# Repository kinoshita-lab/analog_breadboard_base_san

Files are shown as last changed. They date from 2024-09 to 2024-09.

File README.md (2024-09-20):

# Analog Breadboard Base san

[日本語](README.ja.md)

You have two cows. You want to build analog circuit with both positive/negative rails...

Here it is!

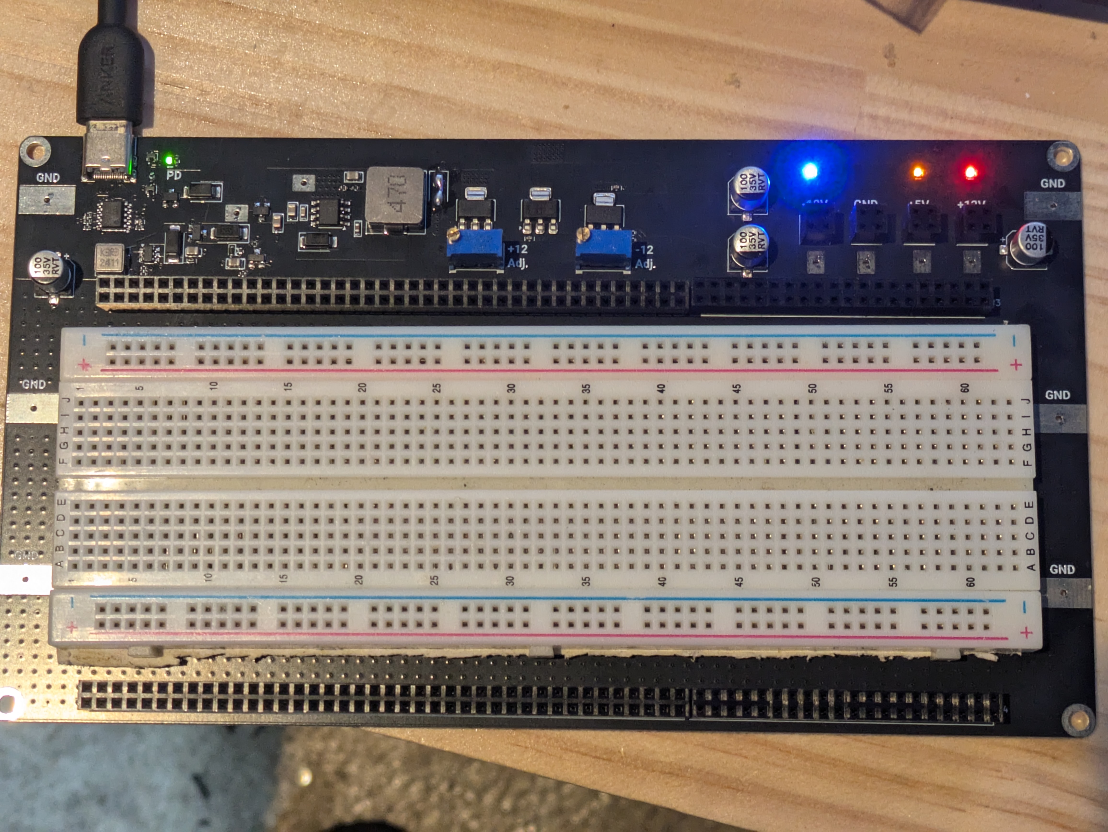
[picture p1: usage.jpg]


## Features

- USB PD supported. Use 15V if the PD power source if available
- When not, internal DC-DC can supply 15V(with a limited power which USB port can supply)
  - Confirmed working with M2 Macbook Air and Chuwi Freebook(meaning you can use this board with normal USB type-C port on your PC)
- Has 15V(unregulated) and -15V(unregulated) test point for the convinience of advanced users..

## Kit Contents

- Pre-assembled circuit board
- 2x2 pin socket connector(4 pcs.)
- 2x40 pin socket connector(2 pcs.)
- 2x20 pin socket connector(2 pcs.)

## What you will need

- USB Type-C Adapter(PD 15V supported)
- 2mm flat head screwdriver
- Multimeter

## How to assemble

- Solder the included connectors to the appropriate places on the circuit board.
- Connect USB Type-C adapter to the PCB and adjust both +12 and -12 potentiometer with screwdriver.

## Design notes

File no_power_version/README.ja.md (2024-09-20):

# GND強化ブレッドボードベースちゃん



## キットに含まれるもの

- 基板
- 2x2 ピンソケット (4個)
- 2x40 ピンソケット (2個)
- 2x20 ピンソケット (2個)

## 必要なもの

- 電源

## 組み立て方

- 付属のコネクターを基板にはんだづけします。

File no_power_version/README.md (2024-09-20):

# GND Enhanced Breadboard Base chan

[日本語](README.ja.md)



## Kit Contents

- Print circuit board
- 2x2 pin socket connector(4 pcs.)
- 2x40 pin socket connector(2 pcs.)
- 2x20 pin socket connector(2 pcs.)

## What you will need

- Appropriate Power Source

## How to assemble

- Solder the included connectors to the appropriate places on the circuit board.

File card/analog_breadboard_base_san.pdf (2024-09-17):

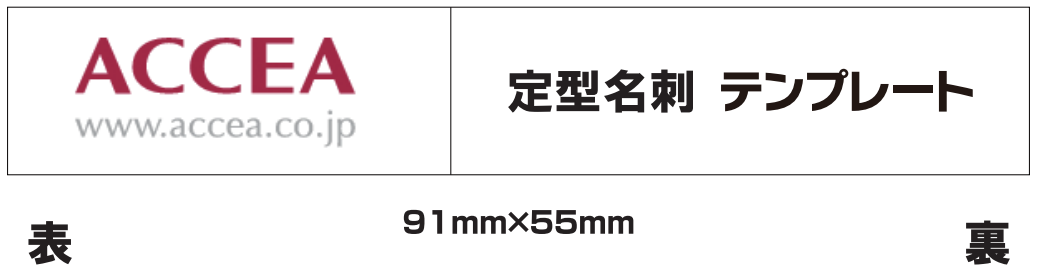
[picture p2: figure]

# https://is.gd/l7i0ia

「アナログBBベースさん」
を購入いただき、
ありがとうございます。説明は、
以下のURLをご参照ください。
https://v.gd/6a0lQR

木下研究所

「アナログBBベースさん」
を購入いただき、
ありがとうございます。説明は、
以下のURLをご参照ください。
https://v.gd/6a0lQR

木下研究所

「アナログBBベースさん」
を購入いただき、
ありがとうございます。説明は、
以下のURLをご参照ください。
https://v.gd/6a0lQR

木下研究所

「アナログBBベースさん」
を購入いただき、
ありがとうございます。説明は、
以下のURLをご参照ください。
https://v.gd/6a0lQR

木下研究所

Thank you so much for buying
“Analog BB Base san”!
Please refer to the following QR URL for how to assemble, what you will need, etc.

### Kinoshita Laboratory

https://v.gd/6a0lQR

Thank you so much for buying
“Analog BB Base san”!
Please refer to the following QR URL for how to assemble, what you will need, etc.

### Kinoshita Laboratory

https://v.gd/6a0lQR

Thank you so much for buying
“Analog BB Base san”!
Please refer to the following QR URL for how to assemble, what you will need, etc.

### Kinoshita Laboratory

https://v.gd/6a0lQR

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

### Kinoshita Laboratory

https://v.gd/6a0lQR

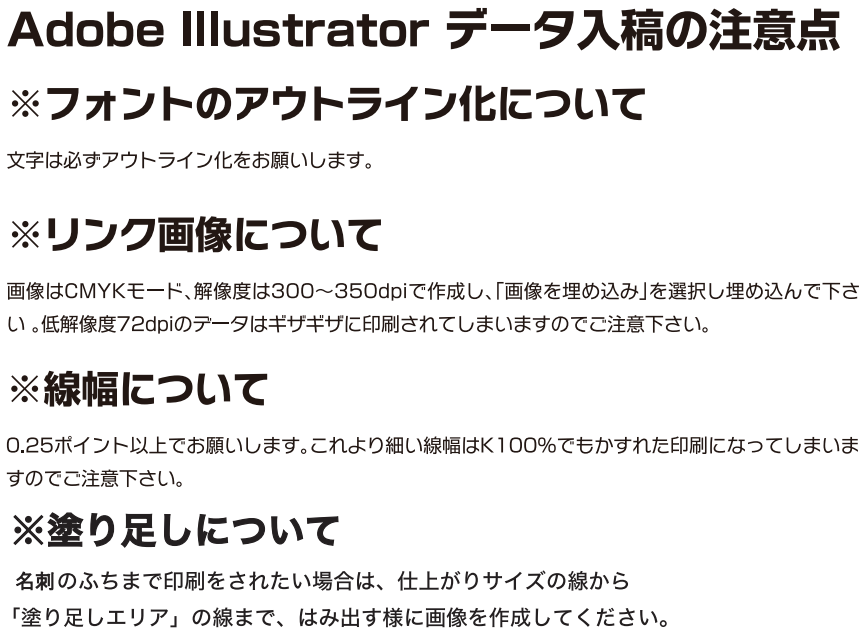
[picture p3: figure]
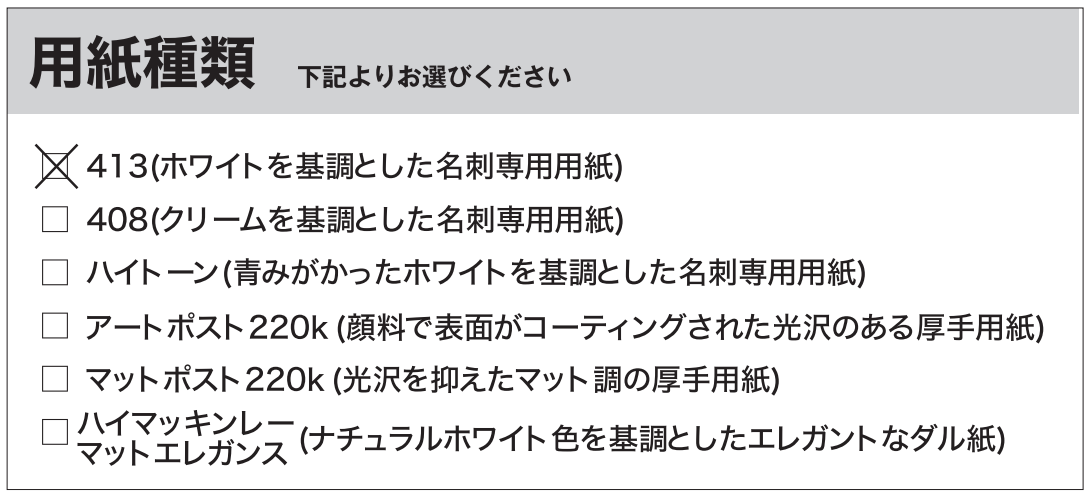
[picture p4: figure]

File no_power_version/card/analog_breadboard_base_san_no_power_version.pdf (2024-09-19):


# https://is.gd/l7i0ia

Thank you so much for buying
“GND Enhanced Breadboard Base chan”! Please refer to the following QR URL for how to assemble, what you will need, etc.

### Kinoshita Laboratory

https://v.gd/OfhjT8

Thank you so much for buying
“GND Enhanced Breadboard Base chan”! Please refer to the following QR URL for how to assemble, what you will need, etc.

### Kinoshita Laboratory

https://v.gd/OfhjT8

Thank you so much for buying
“GND Enhanced Breadboard Base chan”! Please refer to the following QR URL for how to assemble, what you will need, etc.

### Kinoshita Laboratory

https://v.gd/OfhjT8

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

### Kinoshita Laboratory

https://v.gd/OfhjT8

「GND強化BBベースちゃん」
を購入いただき、
ありがとうございます。説明は、
以下のURLをご参照ください。

木下研究所

https://v.gd/OfhjT8

「GND強化BBベースちゃん」
を購入いただき、
ありがとうございます。説明は、
以下のURLをご参照ください。

木下研究所

https://v.gd/OfhjT8

「GND強化BBベースちゃん」
を購入いただき、
ありがとうございます。説明は、
以下のURLをご参照ください。

木下研究所

https://v.gd/OfhjT8

「GND強化BBベースちゃん」
を購入いただき、
ありがとうございます。説明は、
以下のURLをご参照ください。

木下研究所

https://v.gd/OfhjT8


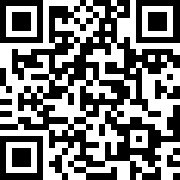
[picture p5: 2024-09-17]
card/QR.png

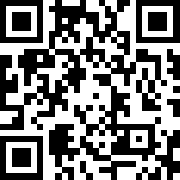
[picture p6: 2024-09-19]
no_power_version/card/QR.png

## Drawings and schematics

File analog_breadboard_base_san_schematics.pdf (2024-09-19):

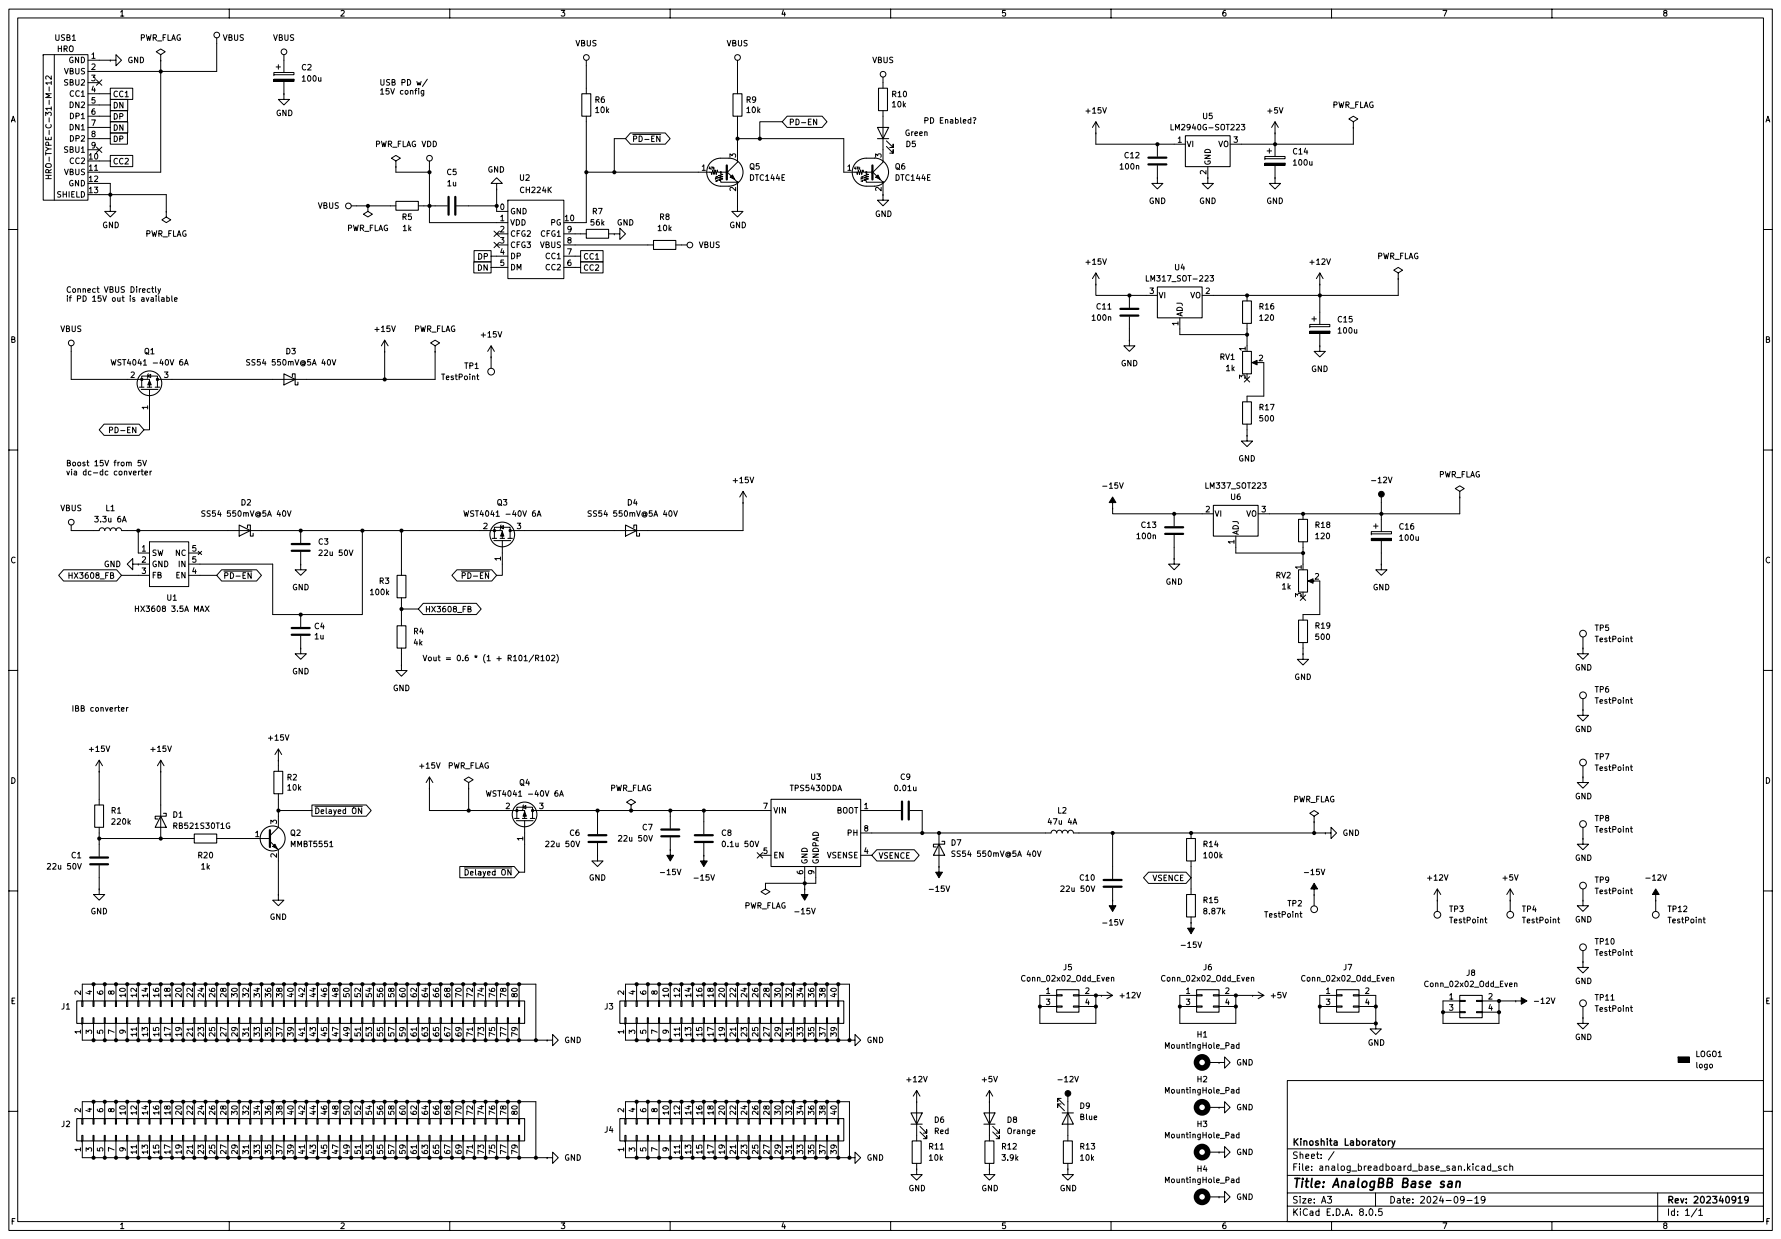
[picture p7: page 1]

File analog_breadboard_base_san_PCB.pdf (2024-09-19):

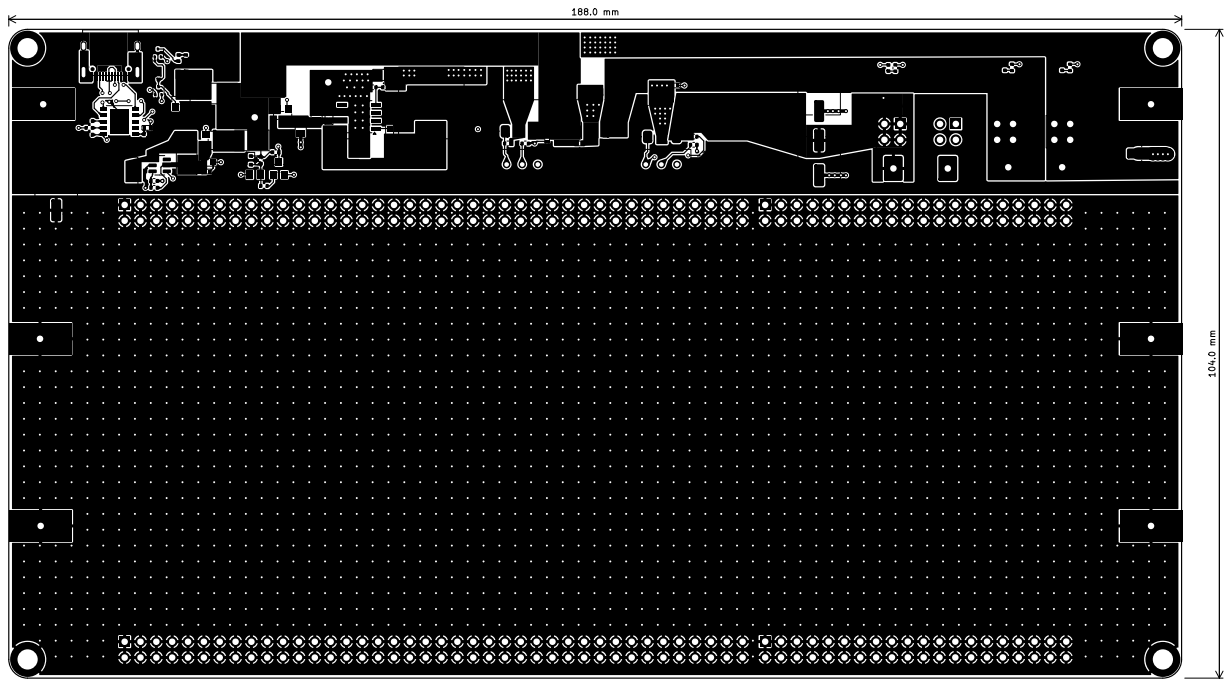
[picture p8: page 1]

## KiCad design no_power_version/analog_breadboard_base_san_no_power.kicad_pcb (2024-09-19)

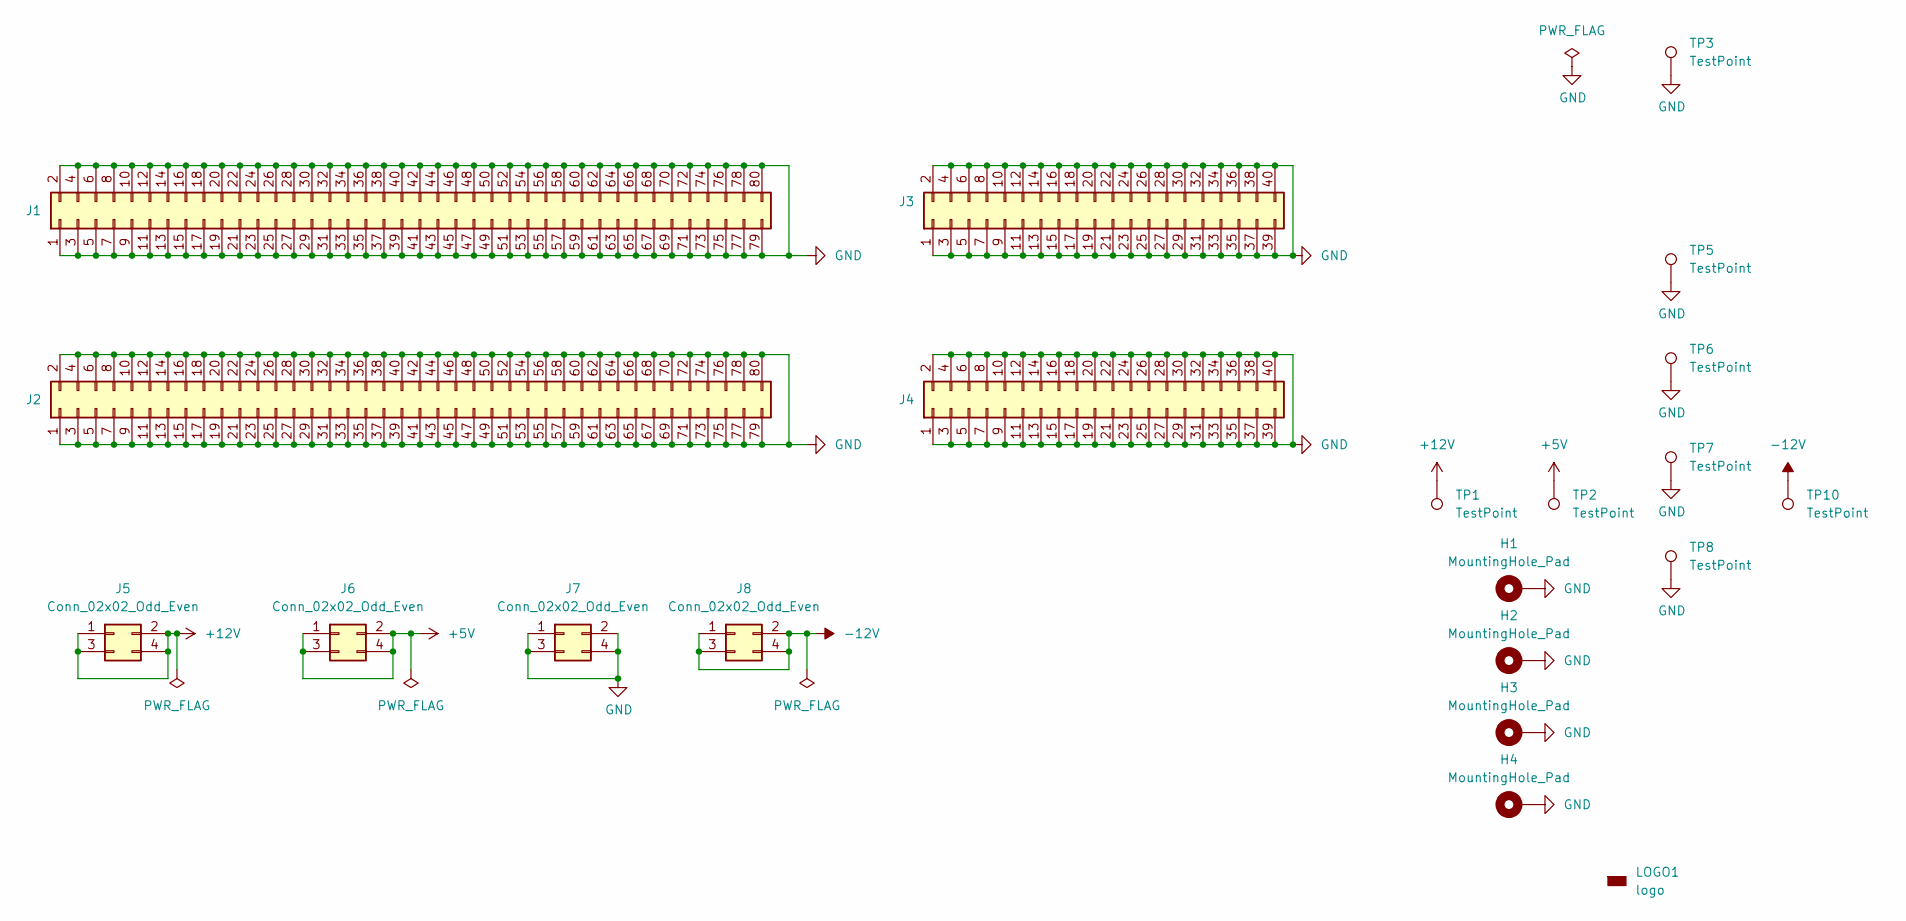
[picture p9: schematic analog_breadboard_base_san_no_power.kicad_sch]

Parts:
H1, H2, H3, H4: MountingHole_Pad; MountingHole_3.2mm_M3_DIN965_Pad
J1, J2: Conn_02x40_Odd_Even; PinSocket_2x40_P2.54mm_Vertical; LCSC C343637
J3, J4: Conn_02x20_Odd_Even; PinSocket_2x20_P2.54mm_Vertical; LCSC C2977589
J5, J6, J7, J8: Conn_02x02_Odd_Even; PinSocket_2x02_P2.54mm_Vertical; LCSC C2977590
LOGO1: logo; kinoshita-logo_simplified_300dpi
TP1, TP2, TP3, TP10: TestPoint; TP_PAD_WITH_HOLE
TP5, TP6, TP7, TP8: TestPoint; TP_PAD_LARGE

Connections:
+5V: J6.1, J6.2, J6.3, J6.4, TP2.1
+12V: J5.1, J5.2, J5.3, J5.4, TP1.1
-12V: J8.1, J8.2, J8.3, J8.4, TP10.1
GND: H1.1, H2.1, H3.1, H4.1, J1.1, J1.2, J1.3, J1.4, J1.5, J1.6, J1.7, J1.8, J1.9, J1.10, J1.11, J1.12, J1.13, J1.14, J1.15, J1.16, J1.17, J1.18, J1.19, J1.20, J1.21, J1.22, J1.23, J1.24, J1.25, J1.26, J1.27, J1.28, J1.29, J1.30, J1.31, J1.32, J1.33, J1.34, J1.35, J1.36, J1.37, J1.38, J1.39, J1.40, J1.41, J1.42, J1.43, J1.44, J1.45, J1.46, J1.47, J1.48, J1.49, J1.50, J1.51, J1.52, J1.53, J1.54, J1.55, J1.56, J1.57, J1.58, J1.59, J1.60, J1.61, J1.62, J1.63, J1.64, J1.65, J1.66, J1.67, J1.68, J1.69, J1.70, J1.71, J1.72, J1.73, J1.74, J1.75, J1.76, J1.77, J1.78, J1.79, J1.80, J2.1, J2.2, J2.3, J2.4, J2.5, J2.6, J2.7, J2.8, J2.9, J2.10, J2.11, J2.12, J2.13, J2.14, J2.15, J2.16, J2.17, J2.18, J2.19, J2.20, J2.21, J2.22, J2.23, J2.24, J2.25, J2.26, J2.27, J2.28, J2.29, J2.30, J2.31, J2.32, J2.33, J2.34, J2.35, J2.36, J2.37, J2.38, J2.39, J2.40, J2.41, J2.42, J2.43, J2.44, J2.45, J2.46, J2.47, J2.48, J2.49, J2.50, J2.51, J2.52, J2.53, J2.54, J2.55, J2.56, J2.57, J2.58, J2.59, J2.60, J2.61, J2.62, J2.63, J2.64, J2.65, J2.66, J2.67, J2.68, J2.69, J2.70, J2.71, J2.72, J2.73, J2.74, J2.75, J2.76, J2.77, J2.78, J2.79, J2.80, J3.1, J3.2, J3.3, J3.4, J3.5, J3.6, J3.7, J3.8, J3.9, J3.10, J3.11, J3.12, J3.13, J3.14, J3.15, J3.16, J3.17, J3.18, J3.19, J3.20, J3.21, J3.22, J3.23, J3.24, J3.25, J3.26, J3.27, J3.28, J3.29, J3.30, J3.31, J3.32, J3.33, J3.34, J3.35, J3.36, J3.37, J3.38, J3.39, J3.40, J4.1, J4.2, J4.3, J4.4, J4.5, J4.6, J4.7, J4.8, J4.9, J4.10, J4.11, J4.12, J4.13, J4.14, J4.15, J4.16, J4.17, J4.18, J4.19, J4.20, J4.21, J4.22, J4.23, J4.24, J4.25, J4.26, J4.27, J4.28, J4.29, J4.30, J4.31, J4.32, J4.33, J4.34, J4.35, J4.36, J4.37, J4.38, J4.39, J4.40, J7.1, J7.2, J7.3, J7.4, TP3.1, TP5.1, TP6.1, TP7.1, TP8.1

Board: 2 copper layers, 21 parts (1 on the bottom side), 4 nets, no tracks yet.

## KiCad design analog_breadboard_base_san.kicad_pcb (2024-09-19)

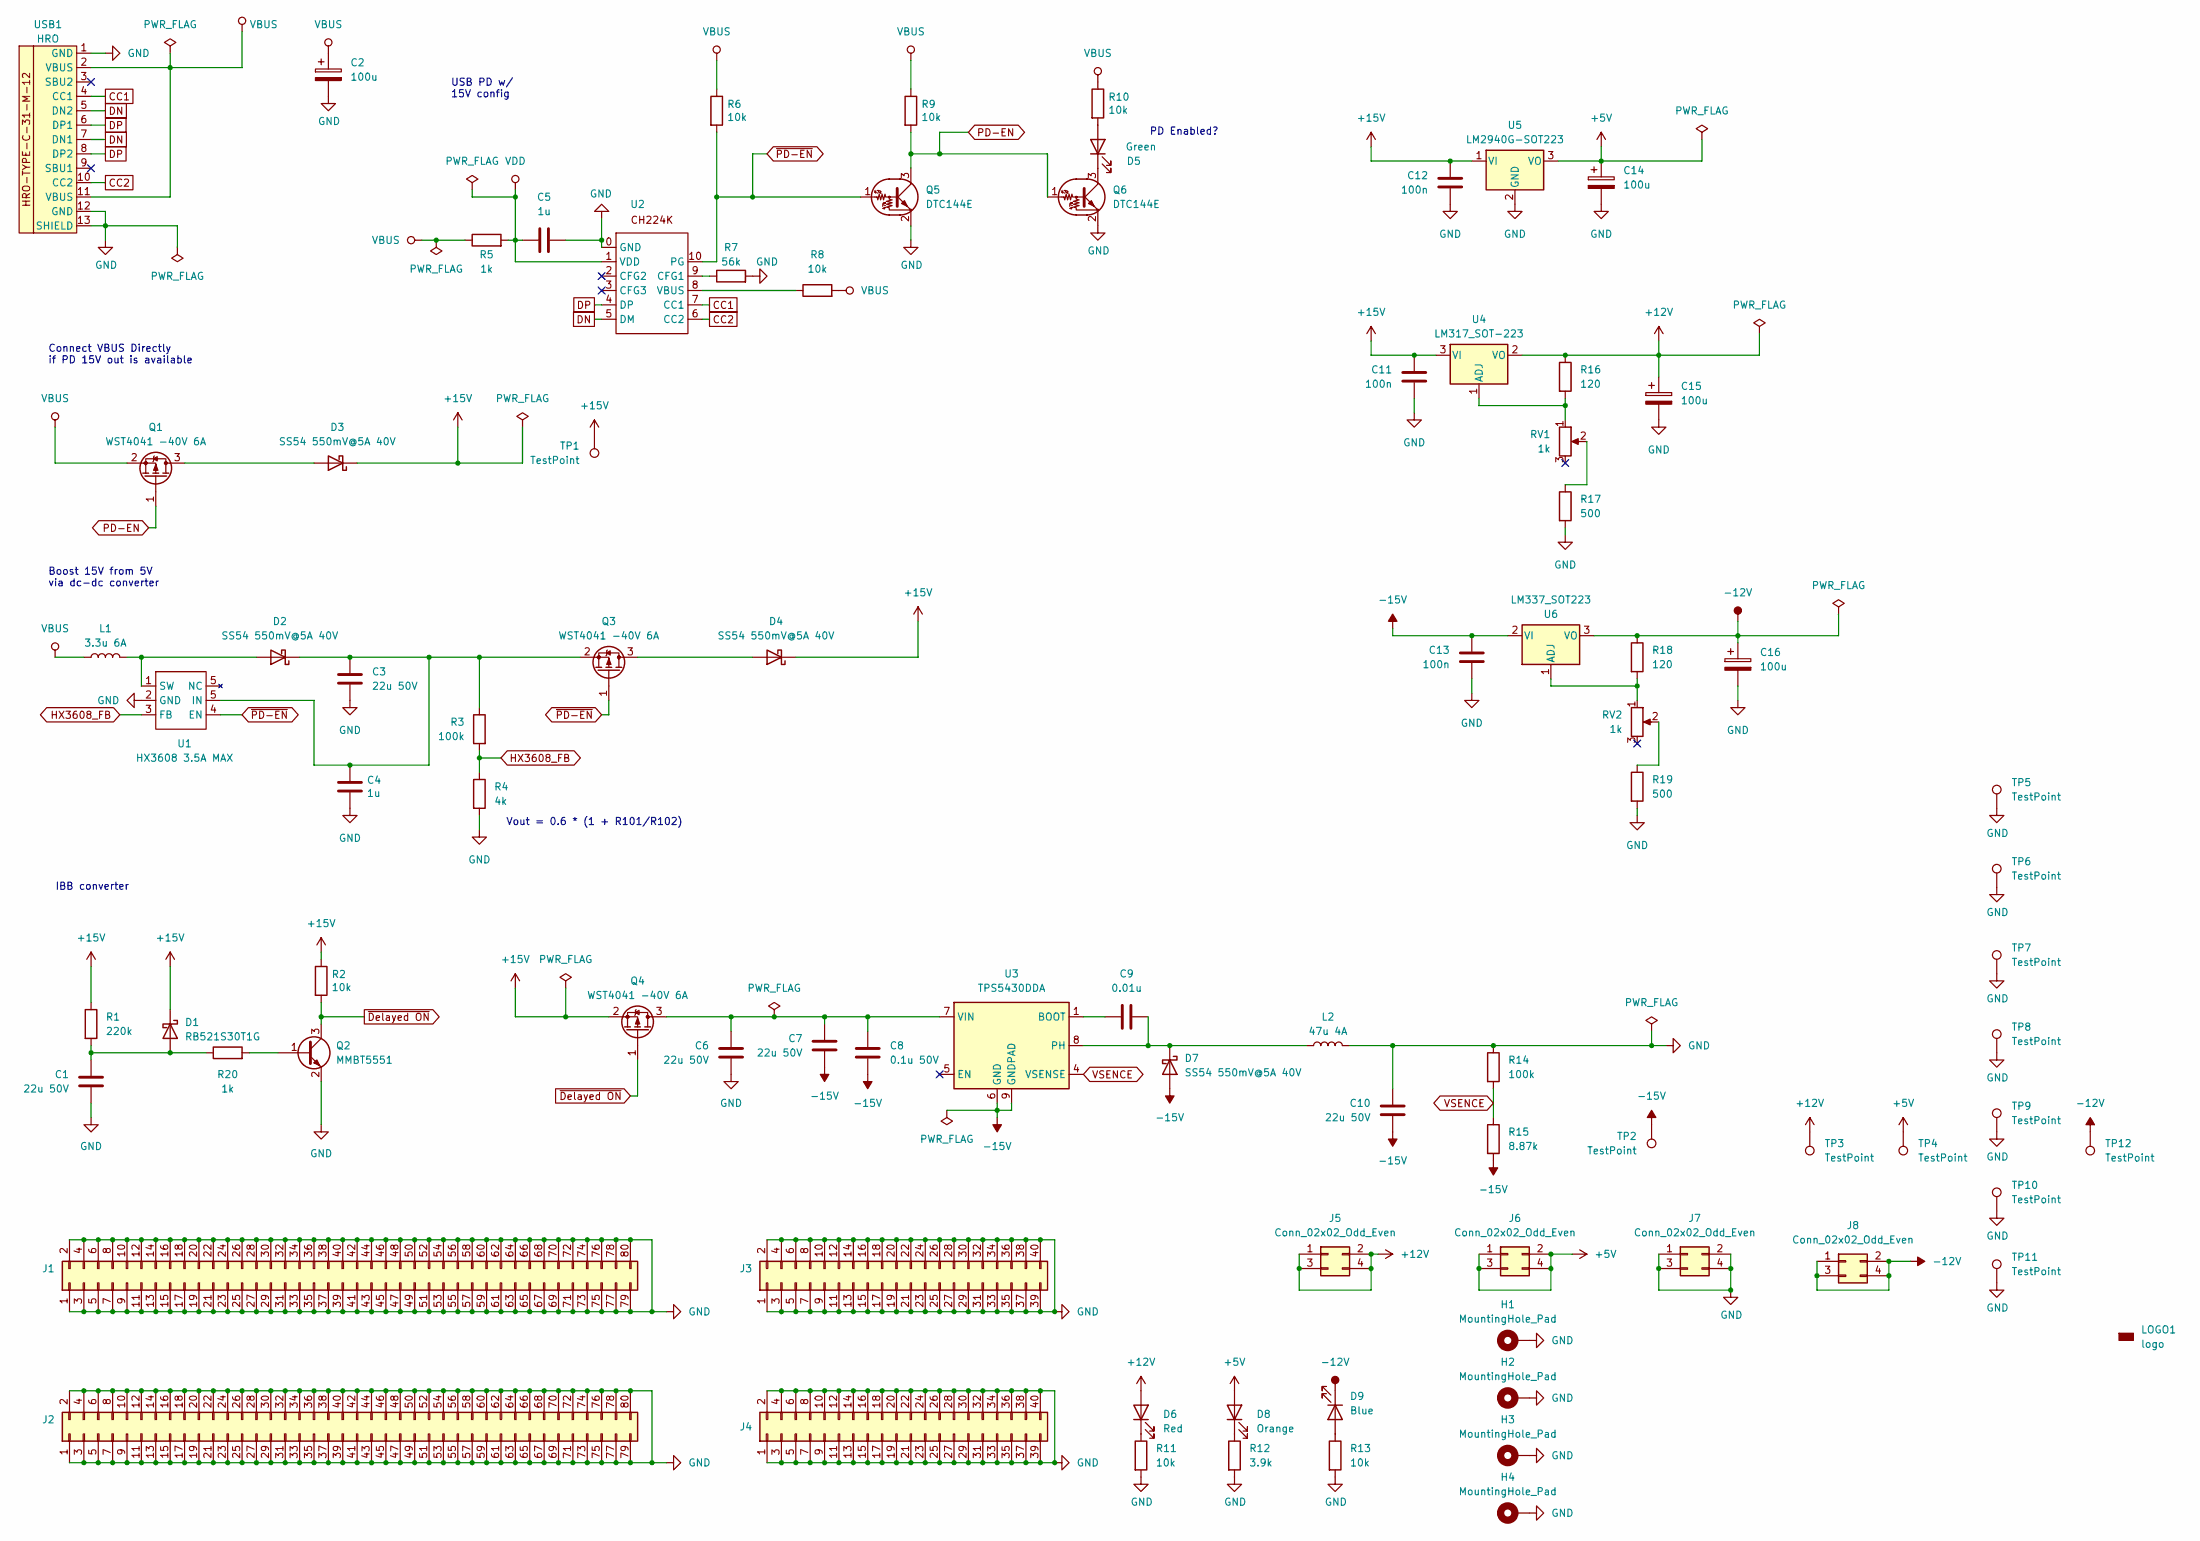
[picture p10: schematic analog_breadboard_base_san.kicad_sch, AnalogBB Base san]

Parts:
C1, C6, C7, C10: 22u 50V; C0805; LCSC C22367832
C2, C14, C15, C16: 100u; CP_Elec_6.3x5.4; LCSC C72478
C3: 22u 50V; C0603; LCSC C22367832
C4, C5: 1u; C0402; LCSC C14445
C8: 0.1u 50V; C0603; LCSC C1591
C9: 0.01u; C0603; LCSC C387983
C11, C12, C13: 100n; C0402; LCSC C56392
D1: RB521S30T1G; D_SOD-523; LCSC C145179
D2, D3, D4, D7: SS54 550mV@5A 40V; D_SMA; LCSC C727065
D5: Green; LED_0402_1005Metric_Enhanced_Cathode; LCSC C434449
D6: Red; LED_0402_1005Metric_Enhanced_Cathode; LCSC C434445
D8: Orange; LED_0402_1005Metric_Enhanced_Cathode; LCSC C965791
D9: Blue; LED_0402_1005Metric_Enhanced_Cathode; LCSC C434447
H1, H2, H3, H4: MountingHole_Pad; MountingHole_3.2mm_M3_DIN965_Pad
J1, J2: Conn_02x40_Odd_Even; PinSocket_2x40_P2.54mm_Vertical; LCSC C343637
J3, J4: Conn_02x20_Odd_Even; PinSocket_2x20_P2.54mm_Vertical; LCSC C2977589
J5, J6, J7, J8: Conn_02x02_Odd_Even; PinSocket_2x02_P2.54mm_Vertical; LCSC C2977590
L1: 3.3u 6A; Inductor_SMD_5.2x5.7; LCSC C2847476
L2: 47u 4A; Inductor_SMD_11.5x10.5; LCSC C20415550
LOGO1: logo; kinoshita-logo_simplified_300dpi
Q1, Q3, Q4: WST4041 -40V 6A; SOT-23; LCSC C148357
Q2: MMBT5551; SOT-23; LCSC C2145
Q5, Q6: DTC144E; SOT-523; LCSC C242410
R1: 220k; R_0402_1005Metric; LCSC C25767
R2, R6, R8, R9, R10, R11, R13: 10k; R_0402_1005Metric; LCSC C25744
R3: 100k; R_0402_1005Metric; LCSC C60491
R4: 4k; R_0402_1005Metric; LCSC C51721
R5, R20: 1k; R_0402_1005Metric; LCSC C11702
R7: 56k; R_0402_1005Metric; LCSC C25796
R12: 3.9k; R_0402_1005Metric; LCSC C51721
R14: 100k; R_0402_1005Metric; LCSC C25530
R15: 8.87k; R_0402_1005Metric; LCSC C155696
R16, R18: 120; R_0402_1005Metric; LCSC C25079
R17, R19: 500; R_0402_1005Metric; LCSC C25167
RV1, RV2: 1k; POT_BOCHEN 3296W C118963; LCSC C118949
TP1, TP2, TP3, TP4, TP5, TP12: TestPoint; TP_PAD_WITH_HOLE
TP6, TP7, TP8, TP9, TP10, TP11: TestPoint; TP_PAD_LARGE
U1: HX3608 3.5A MAX; SOT-23-6; LCSC C296278
U2: CH224K; ESSOP-10_3.9x4.9mm_P1.00mm; LCSC C970725
U3: TPS5430DDA; TI_SO-PowerPAD-8_ThermalVias; LCSC C9864
U4: LM317_SOT-223; SOT-223-3_TabPin2; LCSC C347367
U5: LM2940G-SOT223; SOT-223-3_TabPin2; LCSC C71094
U6: LM337_SOT223; SOT-223-3_TabPin2; LCSC C527400
USB1: HRO; Conn USB TYPE-C16P3MDDGP073 C2965608; LCSC C2965608

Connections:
+5V: C14.1, D8.2 (A), J6.1, J6.2, J6.3, J6.4, TP4.1, U5.3 (VO)
+12V: C15.1, D6.2 (A), J5.1, J5.2, J5.3, J5.4, R16.1, TP3.1, U4.2 (VO)
+15V: C11.2, C12.2, D1.1 (K), D3.1 (K), D4.1 (K), Q4.2 (S), R1.1, R2.1, TP1.1, U4.3 (VI), U5.1 (VI)
-12V: C16.1, D9.1 (K), J8.1, J8.2, J8.3, J8.4, R18.1, TP12.1, U6.3 (VO)
-15V: C7.2, C8.1, C10.2, C13.2, D7.2 (A), R15.2, TP2.1, U3.6 (GND), U3.9 (GNDPAD), U6.2 (VI)
CC1: U2.7 (CC1), USB1.4 (CC1)
CC2: U2.6 (CC2), USB1.10 (CC2)
DN: U2.5 (DM), USB1.5 (DN2), USB1.7 (DN1)
DP: U2.4 (DP), USB1.6 (DP1), USB1.8 (DP2)
GND: C1.2, C2.2, C3.2, C4.2, C5.2, C6.2, C10.1, C11.1, C12.1, C13.1, C14.2, C15.2, C16.2, H1.1, H2.1, H3.1, H4.1, J1.1, J1.2, J1.3, J1.4, J1.5, J1.6, J1.7, J1.8, J1.9, J1.10, J1.11, J1.12, J1.13, J1.14, J1.15, J1.16, J1.17, J1.18, J1.19, J1.20, J1.21, J1.22, J1.23, J1.24, J1.25, J1.26, J1.27, J1.28, J1.29, J1.30, J1.31, J1.32, J1.33, J1.34, J1.35, J1.36, J1.37, J1.38, J1.39, J1.40, J1.41, J1.42, J1.43, J1.44, J1.45, J1.46, J1.47, J1.48, J1.49, J1.50, J1.51, J1.52, J1.53, J1.54, J1.55, J1.56, J1.57, J1.58, J1.59, J1.60, J1.61, J1.62, J1.63, J1.64, J1.65, J1.66, J1.67, J1.68, J1.69, J1.70, J1.71, J1.72, J1.73, J1.74, J1.75, J1.76, J1.77, J1.78, J1.79, J1.80, J2.1, J2.2, J2.3, J2.4, J2.5, J2.6, J2.7, J2.8, J2.9, J2.10, J2.11, J2.12, J2.13, J2.14, J2.15, J2.16, J2.17, J2.18, J2.19, J2.20, J2.21, J2.22, J2.23, J2.24, J2.25, J2.26, J2.27, J2.28, J2.29, J2.30, J2.31, J2.32, J2.33, J2.34, J2.35, J2.36, J2.37, J2.38, J2.39, J2.40, J2.41, J2.42, J2.43, J2.44, J2.45, J2.46, J2.47, J2.48, J2.49, J2.50, J2.51, J2.52, J2.53, J2.54, J2.55, J2.56, J2.57, J2.58, J2.59, J2.60, J2.61, J2.62, J2.63, J2.64, J2.65, J2.66, J2.67, J2.68, J2.69, J2.70, J2.71, J2.72, J2.73, J2.74, J2.75, J2.76, J2.77, J2.78, J2.79, J2.80, J3.1, J3.2, J3.3, J3.4, J3.5, J3.6, J3.7, J3.8, J3.9, J3.10, J3.11, J3.12, J3.13, J3.14, J3.15, J3.16, J3.17, J3.18, J3.19, J3.20, J3.21, J3.22, J3.23, J3.24, J3.25, J3.26, J3.27, J3.28, J3.29, J3.30, J3.31, J3.32, J3.33, J3.34, J3.35, J3.36, J3.37, J3.38, J3.39, J3.40, J4.1, J4.2, J4.3, J4.4, J4.5, J4.6, J4.7, J4.8, J4.9, J4.10, J4.11, J4.12, J4.13, J4.14, J4.15, J4.16, J4.17, J4.18, J4.19, J4.20, J4.21, J4.22, J4.23, J4.24, J4.25, J4.26, J4.27, J4.28, J4.29, J4.30, J4.31, J4.32, J4.33, J4.34, J4.35, J4.36, J4.37, J4.38, J4.39, J4.40, J7.1, J7.2, J7.3, J7.4, L2.2, Q2.2 (E), Q5.2 (E), Q6.2 (E), R4.2, R7.2, R11.2, R12.2, R13.2, R14.1, R17.2, R19.2, TP5.1, TP6.1, TP7.1, TP8.1, TP9.1, TP10.1, TP11.1, U1.2 (GND), U2.0 (GND), U5.2 (GND), USB1.1 (GND), USB1.12 (GND), USB1.13 (SHIELD)
HX3608_FB: R3.2, R4.1, U1.3 (FB)
unnamed: C1.1, D1.2 (A), R1.2, R20.1
unnamed: D2.2 (A), L1.2, U1.1 (SW)
unnamed: C3.1, C4.1, D2.1 (K), Q3.2 (S), R3.1, U1.5 (IN)
unnamed: D3.2 (A), Q1.3 (D)
unnamed: D4.2 (A), Q3.3 (D)
unnamed: D5.2 (A), R10.2
unnamed: D5.1 (K), Q6.3 (C)
unnamed: D6.1 (K), R11.1
unnamed: C9.2, D7.1 (K), L2.1, U3.8 (PH)
unnamed: D8.1 (K), R12.1
unnamed: D9.2 (A), R13.1
unnamed: Q2.1 (B), R20.2
unnamed: C6.1, C7.1, C8.2, Q4.3 (D), U3.7 (VIN)
unnamed: R17.1, RV1.2
unnamed: R19.1, RV2.2
unnamed: R7.1, U2.9 (CFG1)
unnamed: R8.1, U2.8 (VBUS)
unnamed: C9.1, U3.1 (BOOT)
unnamed: R16.2, RV1.1, U4.1 (ADJ)
unnamed: R18.2, RV2.1, U6.1 (ADJ)
PD-EN: Q1.1 (G), Q5.3 (C), Q6.1 (B), R9.2
VBUS: C2.1, L1.1, Q1.2 (S), R5.1, R6.1, R8.2, R9.1, R10.1, USB1.2 (VBUS), USB1.11 (VBUS)
VDD: C5.1, R5.2, U2.1 (VDD)
VSENCE: R14.2, R15.1, U3.4 (VSENSE)
~Delayed ON: Q2.3 (C), Q4.1 (G), R2.2
~PD-EN: Q3.1 (G), Q5.1 (B), R6.2, U1.4 (EN), U2.10 (PG)

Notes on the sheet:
IBB converter
USB PD w/ 15V config
Connect VBUS Directly if PD 15V out is available
Vout = 0.6 * (1 + R101/R102)
Boost 15V from 5V via dc-dc converter
PD Enabled?

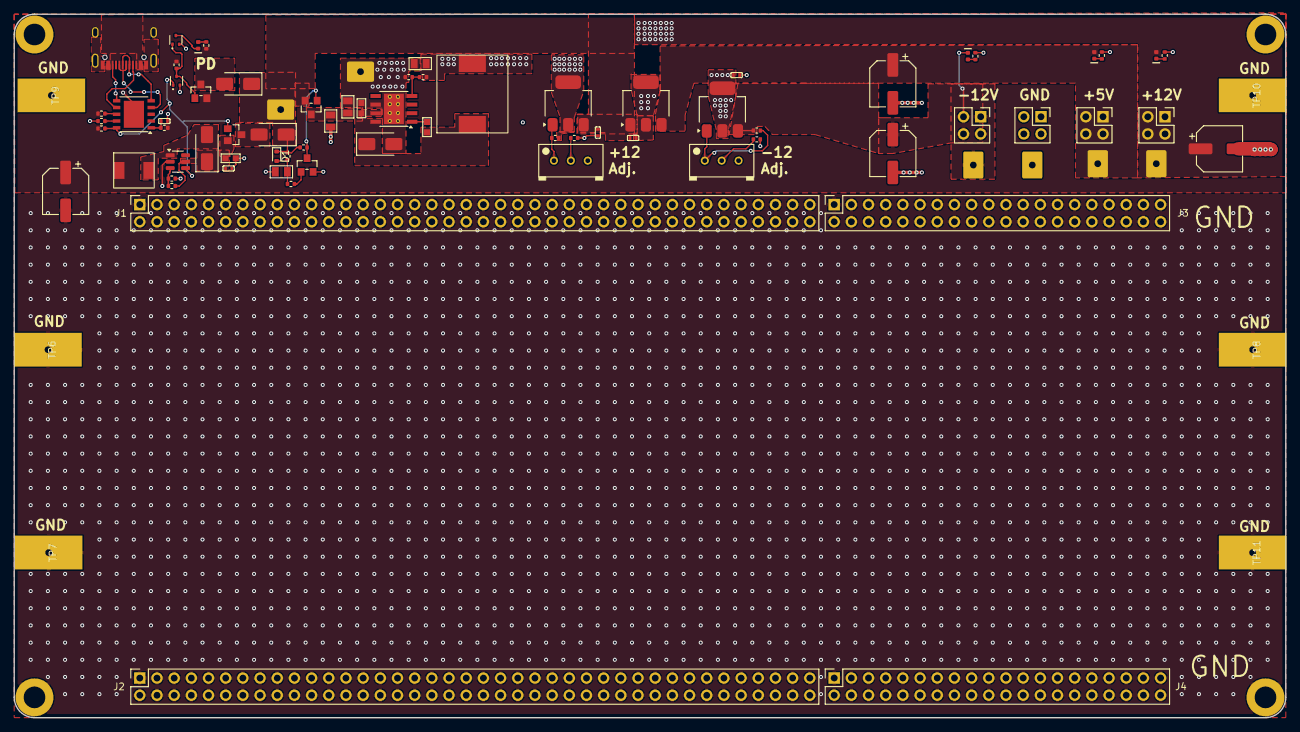
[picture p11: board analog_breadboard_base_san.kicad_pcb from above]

Board: 2 copper layers, 188.0 x 104.0 mm, 87 parts (1 on the bottom side), 37 nets.

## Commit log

2024-09-19 add kicad files
    [analog_breadboard_base_san.kicad_pcb, analog_breadboard_base_san.kicad_sch, analog_breadboard_base_san_no_power.kicad_pcb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]
2024-09-20 add how to assemble
2024-09-20 Add doc for no power version
